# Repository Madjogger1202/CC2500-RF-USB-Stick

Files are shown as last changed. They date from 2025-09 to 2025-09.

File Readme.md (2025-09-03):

# CC2500-RF-USB-Stick  

> USB RF transceiver stick based on **CC2500RGPR** and **FT4222H** (USB↔SPI bridge).  
> Implemented as a **USB flash-drive style dongle** with on-board PCB antenna.  

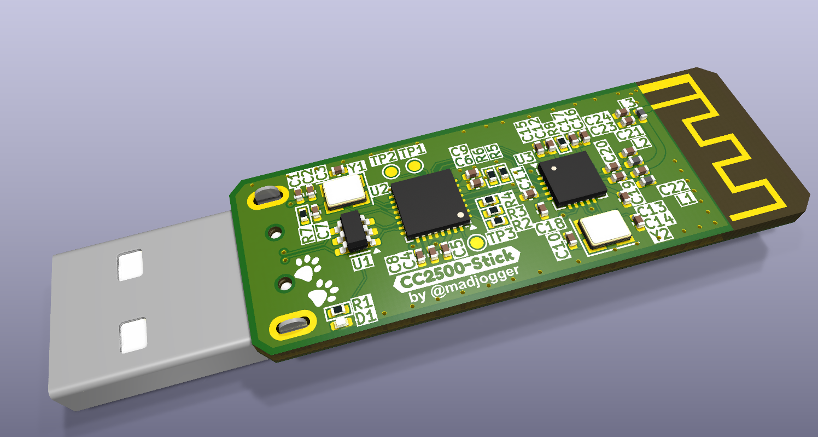
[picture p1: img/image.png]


---

## What’s on the board  
- **FT4222H USB-SPI bridge**  
  - Provides standard SPI master interface over USB  
  - Enumerates as USB device (driver support in Windows/Linux)  
- **CC2500RGPR RF transceiver**  
  - Sub-1 GHz / 2.4 GHz ISM band  
  - Connected directly to FT4222H SPI  
  - Standard configuration mode supported  
- **PCB antenna** integrated into board  
- **USB 2.0 Type-A plug** (flash-stick style)  
- Power from USB bus only (no external supply)  

---

## Pinout (FT4222H ↔ CC2500)  

| FT4222H Pin | CC2500 Pin | Notes |
|---|---|---|
| SCLK | SCLK | SPI clock |
| MOSI | SI | SPI data out |
| MISO | SO | SPI data in |
| CS0  | CSn  | Chip select |
| X | GDO0/GDO2 | Interrupt / status lines |

---

## Power & Form Factor  
- Powered directly from **USB Type-A**  
- Compact PCB with integrated RF antenna  
- No extra components required to operate  

---

## Use Case  
- RF packet capture and transmission via **CC2500**  
- USB plug-and-play stick for wireless experiments  
- Can be used in custom RF tools, sniffers, IoT gateways  

---

## Quick Use  
1. Plug **CC2500-RF-USB-Stick** into USB port.  
2. Install FT4222H driver (if required).  
3. Use SPI commands over FT4222H to configure and control CC2500.  
4. Transmit/receive RF packets in 2.4 GHz band.  

---

## Notes  
- PCB antenna may require tuning for optimal performance.  
- CC2500 settings (frequency, modulation, packet format) configurable via SPI.  
- Heat dissipation negligible (low-power device).  

---

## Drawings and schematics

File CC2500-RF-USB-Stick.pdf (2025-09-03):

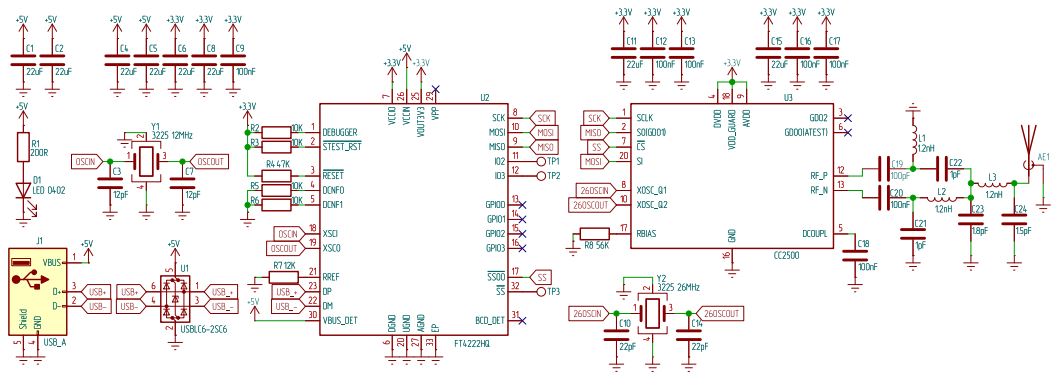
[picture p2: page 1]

þÿ@>2.
þÿ".:>=B@.

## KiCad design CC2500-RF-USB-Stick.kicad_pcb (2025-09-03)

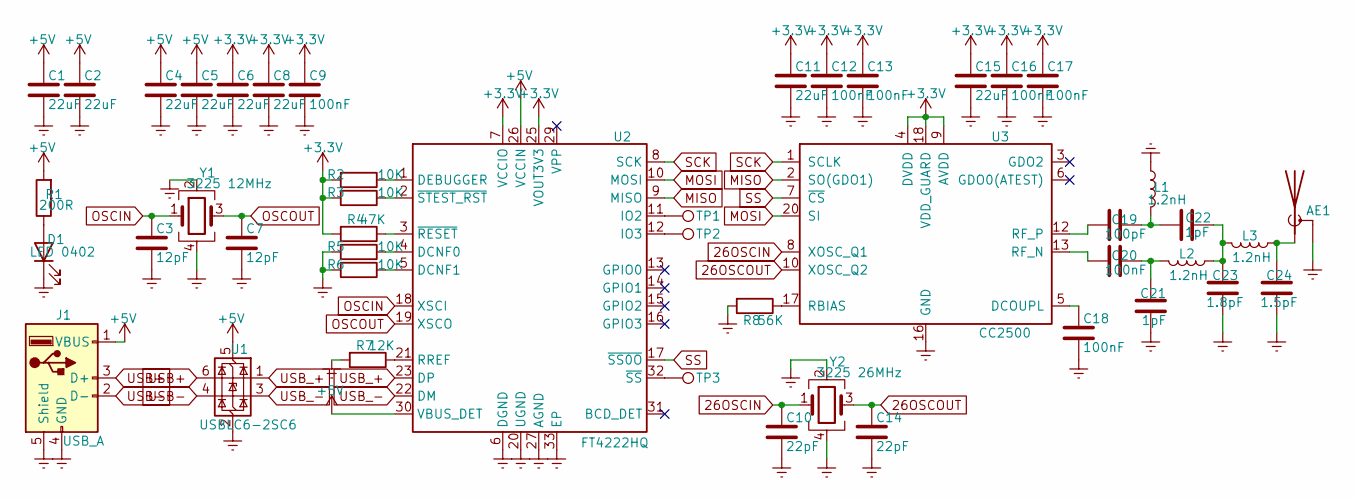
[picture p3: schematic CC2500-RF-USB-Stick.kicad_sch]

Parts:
AE1: Antenna_Shield; Texas_SWRA117D_2.4GHz_Right
C1, C2, C4, C5, C6, C8, C11, C15: 22uF; C_0402_1005Metric
C3, C7: 12pF; C_0402_1005Metric
C9, C12, C13, C16, C17, C18, C20: 100nF; C_0402_1005Metric
C10, C14: 22pF; C_0402_1005Metric
C19: 100pF; C_0402_1005Metric
C21, C22: 1pF; C_0402_1005Metric
C23: 1.8pF; C_0402_1005Metric
C24: 1.5pF; C_0402_1005Metric
D1: LED 0402; LED_0402_1005Metric
J1: USB_A; USB_A_CNCTech_1001-011-01101_Horizontal
L1, L2, L3: 1.2nH; L_0402_1005Metric
R1: 200R; R_0402_1005Metric
R2, R3, R5, R6: 10K; R_0402_1005Metric
R4: 47K; R_0402_1005Metric
R7: 12K; R_0402_1005Metric
R8: 56K; R_0402_1005Metric
TP1, TP2, TP3: TestPoint; TestPoint_Pad_D1.0mm
U1: USBLC6-2SC6; SOT-23-6
U2: FT4222HQ; VQFN-32-1EP_5x5mm_P0.5mm_EP3.1x3.1mm
U3: CC2500; Texas_RGP0020H_VQFN-20-1EP_4x4mm_P0.5mm_EP2.4x2.4mm
Y1: 3225 12MHz; Crystal_SMD_3225-4Pin_3.2x2.5mm
Y2: 3225 26MHz; Crystal_SMD_3225-4Pin_3.2x2.5mm

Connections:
26OSCIN: C10.1, U3.8 (XOSC_Q1), Y2.1
26OSCOUT: C14.1, U3.10 (XOSC_Q2), Y2.3
+3.3V: C6.1, C8.1, C9.1, C11.1, C12.1, C13.1, C15.1, C16.1, C17.1, R2.2, R3.2, R4.2, U2.7 (VCCIO), U2.25 (VOUT3V3), U3.4 (DVDD), U3.9 (AVDD), U3.11 (AVDD), U3.14 (AVDD), U3.15 (AVDD), U3.18 (VDD_GUARD)
+5V: C1.1, C2.1, C4.1, C5.1, J1.1 (VBUS), R1.2, U1.5 (VBUS), U2.26 (VCCIN), U2.30 (VBUS_DET)
Earth: AE1.2 (Shield), C1.2, C2.2, C3.2, C4.2, C5.2, C6.2, C7.2, C8.2, C9.2, C10.2, C11.2, C12.2, C13.2, C14.2, C15.2, C16.2, C17.2, C18.2, C21.1, C23.1, C24.1, D1.1 (K), J1.4 (GND), J1.5 (Shield), L1.1, R5.2, R6.2, R7.2, R8.2, U1.2 (GND), U2.6 (DGND), U2.20 (UGND), U2.24 (UGND), U2.27 (AGND), U2.28 (DGND), U2.33 (EP), U3.16 (GND), U3.19 (GND), U3.21 (GND), Y1.2, Y1.4, Y2.2, Y2.4
MISO: U2.9 (MISO), U3.2 (SO(GDO1))
MOSI: U2.10 (MOSI), U3.20 (SI)
unnamed: AE1.1 (A), C24.2, L3.1
unnamed: C19.2, C22.1, L1.2
unnamed: C20.2, C21.2, L2.2
unnamed: C22.2, C23.2, L2.1, L3.2
unnamed: D1.2 (A), R1.1
unnamed: R5.1, U2.4 (DCNF0)
unnamed: R6.1, U2.5 (DCNF1)
unnamed: R2.1, U2.1 (DEBUGGER)
unnamed: TP1.1, U2.11 (IO2)
unnamed: TP2.1, U2.12 (IO3)
unnamed: R7.1, U2.21 (RREF)
unnamed: R4.1, U2.3 (~RESET)
unnamed: TP3.1, U2.32 (~SS)
unnamed: R3.1, U2.2 (~STEST_RST)
unnamed: C18.1, U3.5 (DCOUPL)
unnamed: R8.1, U3.17 (RBIAS)
unnamed: C20.1, U3.13 (RF_N)
unnamed: C19.1, U3.12 (RF_P)
OSCIN: C3.1, U2.18 (XSCI), Y1.1
OSCOUT: C7.1, U2.19 (XSCO), Y1.3
SCK: U2.8 (SCK), U3.1 (SCLK)
SS: U2.17 (~SS0O), U3.7 (~CS)
USB+: J1.3 (D+), U1.6 (I/O1)
USB-: J1.2 (D-), U1.4 (I/O2)
USB_+: U1.1 (I/O1), U2.23 (DP)
USB_-: U1.3 (I/O2), U2.22 (DM)

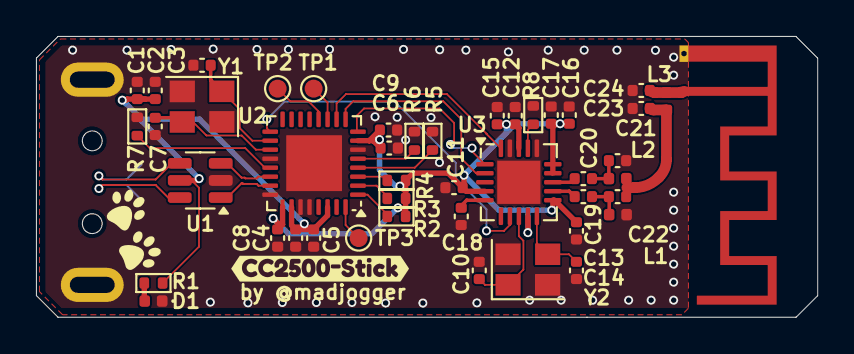
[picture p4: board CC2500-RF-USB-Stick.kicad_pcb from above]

Board: 2 copper layers, 43.4 x 15.6 mm, 47 parts (1 on the bottom side), 33 nets.

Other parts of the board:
kibuzzard-68B8A8C4: G***; kibuzzard-68B8A8C4
